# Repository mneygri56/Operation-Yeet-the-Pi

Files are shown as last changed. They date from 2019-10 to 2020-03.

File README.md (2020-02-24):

# Operation Yeet the Pi
Pi in the sky, by Miles and David. Also the story of how we ended up on several government watchlists.

*******DISCLAIMER, WE ARE DOING THIS UNDER A LOT OF SUPERVISON AND HAVE A LOT OF PEOPLE WHO KNOW WHAT THEY ARE DOING, THIS IS BY NO MEANS AN ENDORSEMENT OF ANY PROJECTS YOU MAY DO, AND THE FACT THAT WE ARE STILL ALIVE DOES NOT MEAN YOU WILL BE, PLEASE, <b>DO NOT TRY THIS AT HOME</b> ********* 

Thats a little aggressive, but it gets the point across, just to reiterate do not try this at home

That being said, here's how we did it
## A bad idea... or maybe not
The plan, if that's what we're going to call it, is to strap a pi onto a homemade rocket engine using [this recipe](https://www.wikihow.com/Make-Rocket-Fuel) for the fuel, and send that up. The final version of the rocket is going to be called the Kerbal XD after the Kerbal X from Kerbal Space Program.
## The Goal
Our goal is to launch a rocket as high as we can and collect data along the whole flight. (What Data to Collect). We are going to do a few tests of different additives of the fuel to increase thrust, and we will use this equation:

<a href="https://www.codecogs.com/eqnedit.php?latex=\LARGE&space;\Delta&space;v&space;=&space;v_{exhaust}*ln(\frac{m_{initial}}{m_{final}})" target="_blank">\LARGE \Delta v = v_{exhaust}*ln(\frac{m_{initial}}{m_{final}})</a>

To calculate how much fuel we should use to maximize delta v. The other values can be calculated from the test we will do and the rocket design. We could also have a height goal so that we can figure out exactly how fast we want the exhaust to go and how much fuel we need.

## Materials
| Material | Quantity | Cost |
|:---:|:---:|:---:|
| Potassium Nitrate(KNO<sub>3</sub>) | 58 grams (2.0 oz) per rocket | ~$7.00 per pound  |
| Granulated White Sugar | 29 grams (1.0 oz) per rocket | ~$2.00 for 4 pounds |
| Karo Corn Syrup |  13 milliliters (.43 floz) per rocket | ~$2.00 for 16 fl oz |
| Distilled Water | 30 milliliters (1.01 floz) per rocket | ~$0.80 for 1 gallon |

Cost = $25.80 Total, not including materials

Cost Turned out to be about $23
## Schedule

- Week One: 10/28 - 10/31
  + Planning: Start Project Plan
- Week Two: 11/6 - 11/8
  + Planning: Finish Project Plan, Seek Approval
    - Make Drawings
    - Do math that supports the design
    - Gather Materials
    - Make SolidWorks Model of Chassis
- Week Three: 11/11 - 11/15
  + Planning: Make Edits To Project Plan, Finalize and Submit
  + Make More Drawings!
- Week Four: 11/18 - 11/22
  + Buy Materials (Potassium Nitrate Specifically)
  + Test Batches - Different Additives and Force Plate
    - Use block period/afterschool
- Week Five: 11/25 - 11/29
  + Start Code: 
    - Make code to start the rocket
  + Revise SolidWorks Model
    - Do a Stress Analysis
    - Make sure there is room for wires
    - Make sure the Pi fits
  + Make predictions about how much fuel should be in the rocket
- Week Six: 12/2 - 12/6
  + Keep Coding:
    - Make Code to Log Acceleration
    - Make Code to Log other things
  + Build the SolidWorks model
    - In Real Life
    - Figure Out Materials
- Week Seven: 12/9 - 12/13
  + Make 2 Batches and Test:
    - Boil 'Em Mash 'Em Stick 'Em in a Stew
    - Don't Actually, its probably toxic
    - Test For lift, how much juice it outputs
- Weeks Eight to Ten:
  + Off For Winter Break and Midterms
- Week Eleven 1/6 - 1/10:
  + Make More Code:
    - Sound At Apex
    - Second Stage Activation and Timing
  + Build Rocket Engines:
    - Housing and Connection
- Week Twelve 1/13 - 1/17:
  + Build the Rocket:
    - Put it together
  + Finish Code:
    - Have the Code that will run on the Rocket
- Week Thirteen 1/20 - 1/24:
  + Assemble First Rocket Completely
    - Test Launch - 3 Motors, not full 6
  + Revise Code After Launch
- Week Fourteen 1/27 - 1/31:
  + Revise Code More:
    - See what worked
  + Revise Design Based on the Launch
    - Again, see what worked
- Week Fifteen 2/3 - 2/7:
  + Launch No. 2 - 4
    - Full 6 Motors
    - 3 Launches
  + Revise Code and Design
- Week Sixteen 2/10 - 2/14:
  + Launch No. 3 - 6
    - Full 6 Motors
    - 3 More 
  + Revise Design and Code
- Week Seventeen 2/17 - 2/21:
  + Launch No. 7-10
    - Full 6 Motors
- Week Eighteen 2/24 - 2/28:
  + Mess around with rocket fuel
    - Stick as many motors on as possible
- Week Nineteen 3/2 - 3/6:
  + Submit and Finish
  + We might be able to combine Eighteen and Nineteen
  
Well, a natural part of the engineering processs is revising. This schedule does not reflect how much testing we have to do, and how long the solidworks would take to finish. I think we have been a bit distracted, but We are still trying to finish by the end date of March 6th.

- Week 14: 1/27-1/31
  + I'd like to finish the solidworks model this week so that we can talk it over with Dr. Shields and finish revising it and print it.
  + Make Rust and Test it
- Week 15: 2/3-2/7
  + Revise the solidworks and hopefully be ready to print it
  + Make some rocket fuel with the rust, try to get 40-50g thrust
- Week 16: 2/10-2/14
  + Finalize the fuel mixture and fill boosters
  + Make sure code is ready to go
  + Prep for launch
- Week 17: 2/17-2/21
  + Get ready to assemble, update wiki with pics and vids
- Week 18: 2/24-2/28
  + David will be gone
  + Prep for launch, print stuff and get ready
- Week 19: 3/2-3/6
  + Launch on wed
  + Cool! Fun
- Week 20:
  + Submit and Finish
## Safety
I know our wikis and stuff are known for a bit of fun and jokes, but this part is serious, professional, and must not be joked around with.

There are multiple danger points in this project. This project can definitely go wrong. We must act with utmost care and respect for all of the forces and materials involved.

### Making the Fuel
This is probably the most dangerous part. We are going to be heating up flammable materials to get them to congeal into a solid block. [Here](https://www.wikihow.com/Make-Rocket-Fuel?scrlybrkr=71c97d6e) is the procedure for making the fuel and [here](http://www.jamesyawn.net/rcandy/safety.htm) is one of the best places to see the risks and danger points involved. The most dangerous part of making the fuel according to this source is scraping the fuel and shaping it. I agree, and we must be careful. Additionally, here more precautions that must be taken:

- Have an ABC fire extinguisher on hand in case fire breaks out. Worst case scenario is that fire breaks out in the pan and we are close to it. The first thing that must be done in case of this is to put out the fire. This reaction is self sustaining and powerful, so we cannot rely on just the heat being turned off.
  - Two people must be on hand while cooking, ideally three. One to cook the mixture, one to get help in case of a fire and the person cooking is incapacitated, and one to put out the fire. All jobs are important, but the two most important are the cooking and putting out the fire, getting help can be taken care of by the person cooking if they are not incapacitated by the fire from the mixture.
- Do all of it outside, it will minimize damage if fire breaks out, and will provide an easy way for the fumes to escape without harming us.
- Store the finished rocket fuel in a plastic container in the storage room if possible, this will reduce the risk of people thinking they can mess with the fuel once we are done. 
### Launches
This is the other part where things can go wrong. A stray launch can go into someone's face with a lot of force, burn a lot of grass, so on and so forth. Here are some additional concerns to be aware of when launching rockets.

- Make sure the launch area is clear and people are standing well back, this will make sure that things do not catch fire, and that people will not be hurt by the launch.
- Launch on pavement if possible - if not, put down a piece of metal or other inflammable material under the launch site, this will reduce the risk of fire from grass under the launch site. Additionally, we may consider using one of those launch platforms so that the launch will be straight, in addition to not catching the grass on fire.
- Keep landing site clear, This is a big one - we don't know where the rocket will land, so if possible, we want to make sure it lands in an unpopulated area, of cars and people, in case a parachute cannot slow it down enough to where it won't break a car's winshield if it lands on it. Additionally, some fuel may be left unreacted, so we don't want it to burn on the ground - Consider putting a gps reciever on it so we can keep track of where it is.
- Put a parachute in the end so that when it starts its downward approach, it won't be going as fast so it is less dangerous.
- Apparently there are rules against putting massive amounts of rocket fuel on plastic and shooting it as high as it will go, so we are only going to use two engines to avoid being sued by the FAA
## Questions to consider
(Put Answers below as we discuss)
- What should we put on the rocket? What do we need?
   - accelerometer
   - Piezo Buzzer
   - Pi
   - Wires
   - Altimeter
   - battery
- What additives should we test?
  - Rust Powder 
- What should we make the chassis out of? The engine housing? Pi camera housing? Others?
  - Metal
  - Foam
  - ABS-PC
- Parachute? If so, how will it deploy? If not, how do we reduce the risk of crashing and burning? Use McIntire Park? Milton Airfield? What permits, if any, will we need to do it at these places?
  - propellor? (probably not)
  - "Nerf Sword" prinicple
    - Plastic Shell covered in foam (metal)
  - actual parachute
- How are we going to reduce weight so it gets as high as possible?
  - Skeletonized Parts
  - Bare Minimum Wires
  - Plastic
## Rocket Specs

### Fuel Info
The fuel is made of Potassium Nitrate, sucrose, and brown iron rust at a ratio of 65:35:1. The general process is to heat up the three ingredients until the sugar and potassium nitrate melt to create a liquidy substance, stirring constantly. The beaker is then taken off the heat and the fuel is scooped into the rocket booster. It is then packed by tamping it with the head of a nail. After talking to a rocket person, This process may be revised to packing the fuel into a cardboard tube to make an engine before actually placing the motor into the ABS-PC receptacle. 

### Grain Geometry
The grain geometry is an important consideration when assessing burn rates and thrust. We have been using a simple flat surface, but we have been considering drilling a hole in the middle of the engine to have larger thrust on liftoff, and the thrust will increase over the flight.

### Fuselage Info
The fuselage is made of a cylinder of ABS PC with a hole in the middle for the raspberry pi, recovery servo, and other sensors. More information is in the solidworks models, or in the pictures section.

### Recovery
We are planning to use a parachute from an estes kit to recover the rocket. The recovery servo will push the platform that the parachute is resting on up so that the parachute will pull away from the top as the rocket slows down at the top of its arc. For this reason, there is no nose cone. This acts as a fail safe if the rocket starts going out of control, the parachute will fall away from the rocket and deploy because the parachute was being held on by the speed that the rocket was going.

### Nozzle
The nozzle is a piece of ABS-PC that covers the end of the engine with a 10mm hole in the middle.

## Sources
I have a feeling I will be referencing this a lot:

Munroe, Randall. “Rocket Golf.” Rocket Golf, Xkcd, [Rocket Golf](what-if.xkcd.com/85/).

Nakka, Richard. “Determining Total Impulse and Specific Impulse from Static Test Data.” Richard Nakka's Experimental Rocketry Site, 2000, [www.nakka-rocketry.net/impcalc.html](www.nakka-rocketry.net/impcalc.html).

## Calculations

<a href="https://www.codecogs.com/eqnedit.php?latex=\LARGE&space;\Delta&space;v&space;=&space;v_{exhaust}*ln(\frac{m_{initial}}{m_{final}})" target="_blank">\Delta v = v_{exhaust}*ln(\frac{m_{initial}}{m_{final}})</a>

<a href="https://www.codecogs.com/eqnedit.php?latex=&space;v_{exhaust}=I_{sp}g_{0}" target="_blank">v_{exhaust}=I_{sp}g_{0}</a>

<a href="https://www.codecogs.com/eqnedit.php?latex=&space;g_0&space;=&space;9.806\frac{m}{s^2}" target="_blank">g_0 = 9.806\frac{m}{s^2}</a>

<a href="https://www.codecogs.com/eqnedit.php?latex=&space;I_{sp}=120s" target="_blank">I_{sp}=120s</a>

<a href="https://www.codecogs.com/eqnedit.php?latex=\LARGE&space;v_{exhaust}=120s*9.806\frac{m}{s^2}=1176.72\frac{m}{s}" target="_blank">v_{exhaust}=120s*9.806\frac{m}{s^2}=1176.72\frac{m}{s}</a>

<a href="https://www.codecogs.com/eqnedit.php?latex=m_{fin}=444g" target="_blank">m_{fin}=444g</a>

<a href="https://www.codecogs.com/eqnedit.php?latex=\Delta&space;v=1176.72ln(\frac{m_{fuel}&plus;444}{444})" target="_blank">\Delta v=1176.72ln(\frac{m_{fuel}+444}{444})</a>

## Some Documentation
### Pictures
Should have started this sooner, but here:

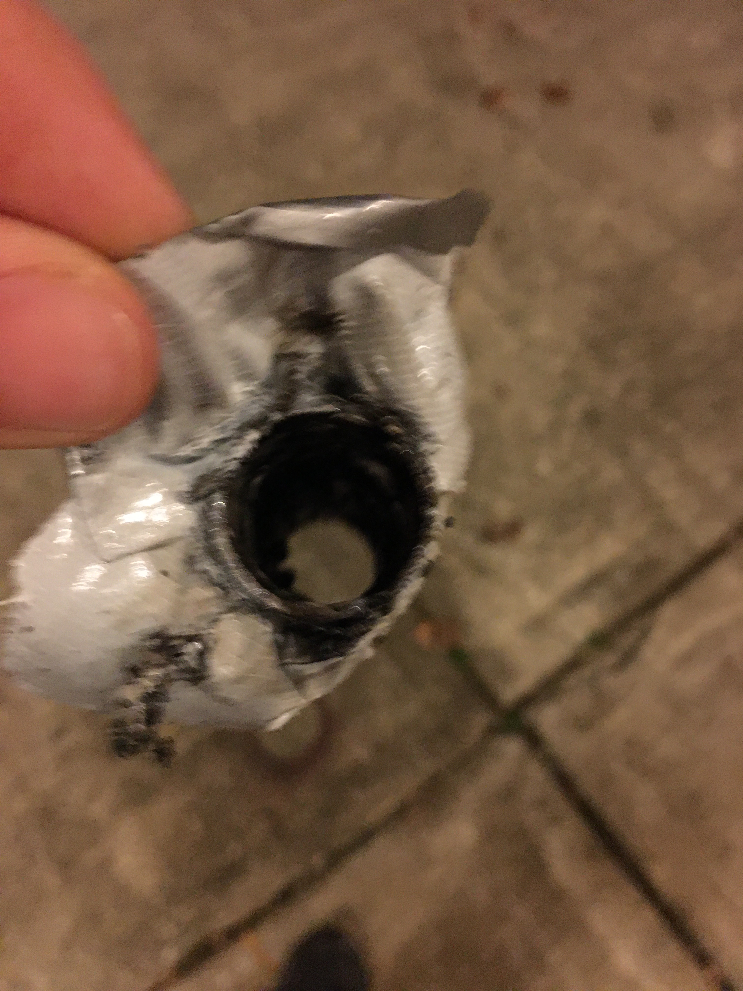
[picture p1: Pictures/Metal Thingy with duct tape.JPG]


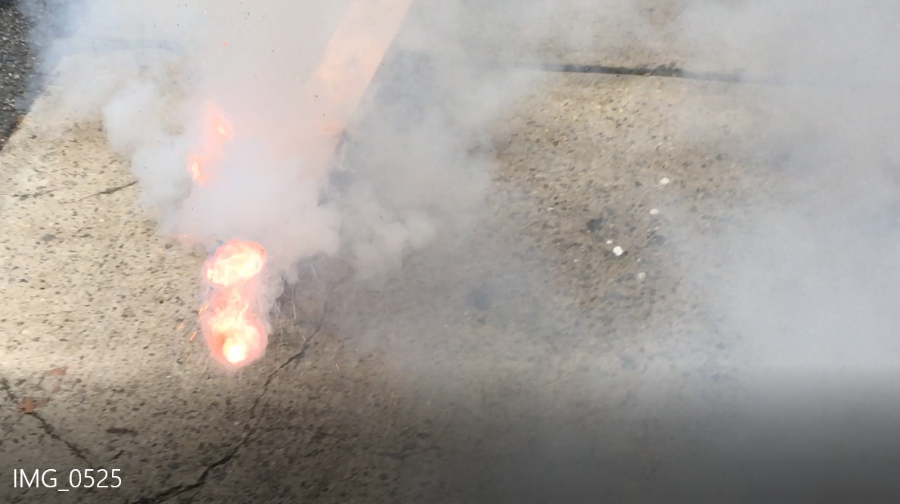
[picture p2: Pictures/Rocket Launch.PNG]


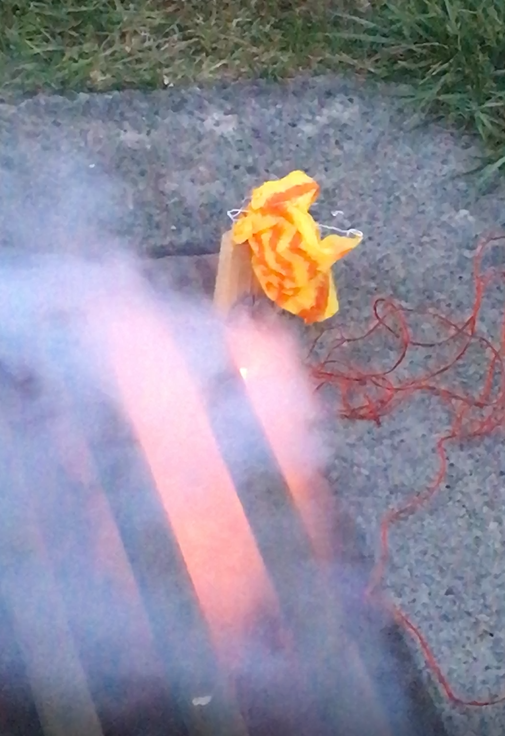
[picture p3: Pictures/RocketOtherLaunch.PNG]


[Making Rust](https://youtu.be/RcKSFwdpVkA)

[Testing Rocket](https://youtu.be/CEroAyz3F4E)

[Another One](https://youtu.be/RToPVv3NRZM)

### Weekly Progress Report
This starts from the first milestone, 11/22

#### 11/22
Well, we made a batch, but it didn't really work. I couldn't really tell you why, but we have a few guesses
- The stuff wasn't dry -very likely
- It doesn't work and we are failures -less likely

It made a really cool firey thing though
#### 11/29
We forgot about thanksgiving break, and we didn't accomplish everything we set out to do. We are thinking we can't start our rocket with the pi, so maybe just use a blowtorch, we'll see if the starters can actually start the rocket fuel, but we might need to use the blowtorch. 

In other news, we got a pretty good model of the rocket in solidworks, all we have to do now is add a servo so that we can take the top off whenever we want to.
#### 12/6
We have most of a solidworks model, its not completely done, but we are close, just having to resolve all these random errors that are weird. We also added a few videos and pictures of a cool launch that finally worked where Dr. Shields almost shot himself in the leg! to the github Cool! Additionally, there is now a bunch of code for logging acceleration data and taking video. We have yet to print the model, but we are still on schedule.
#### 12/13

#### 1/10

#### 1/17
This week, we started revising the solidworks model so that it took the least amount of material to print, and it was as small as possible. We did this so that the boosters could lift the model, and so that it used not that much material. I feel like we are behind schedule, but I'll let it slide.
#### 1/24

#### 1/31

#### 2/7

#### 2/14

#### 2/21

#### 2/28

#### 3/6

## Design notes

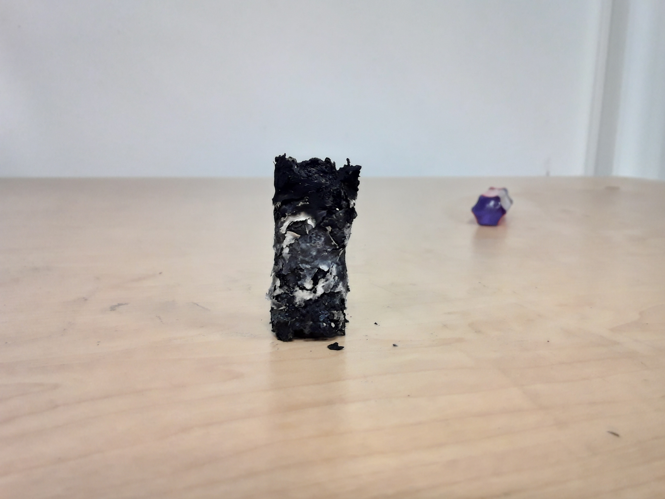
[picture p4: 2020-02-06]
Pictures/Burned out rocket booster, back of a screwdriver for scale.jpg

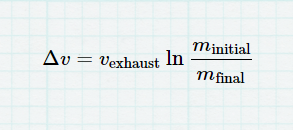
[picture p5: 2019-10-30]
Pictures/RocketEquation.PNG

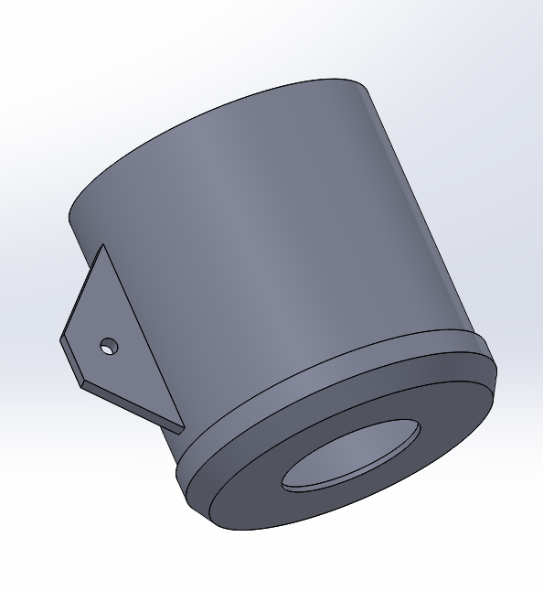
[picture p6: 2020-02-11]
Pictures/Booster.PNG

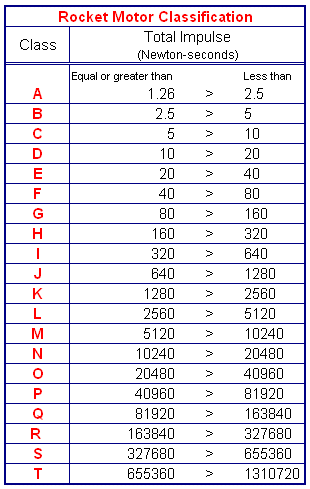
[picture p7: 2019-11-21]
Pictures/mot_clas.gif

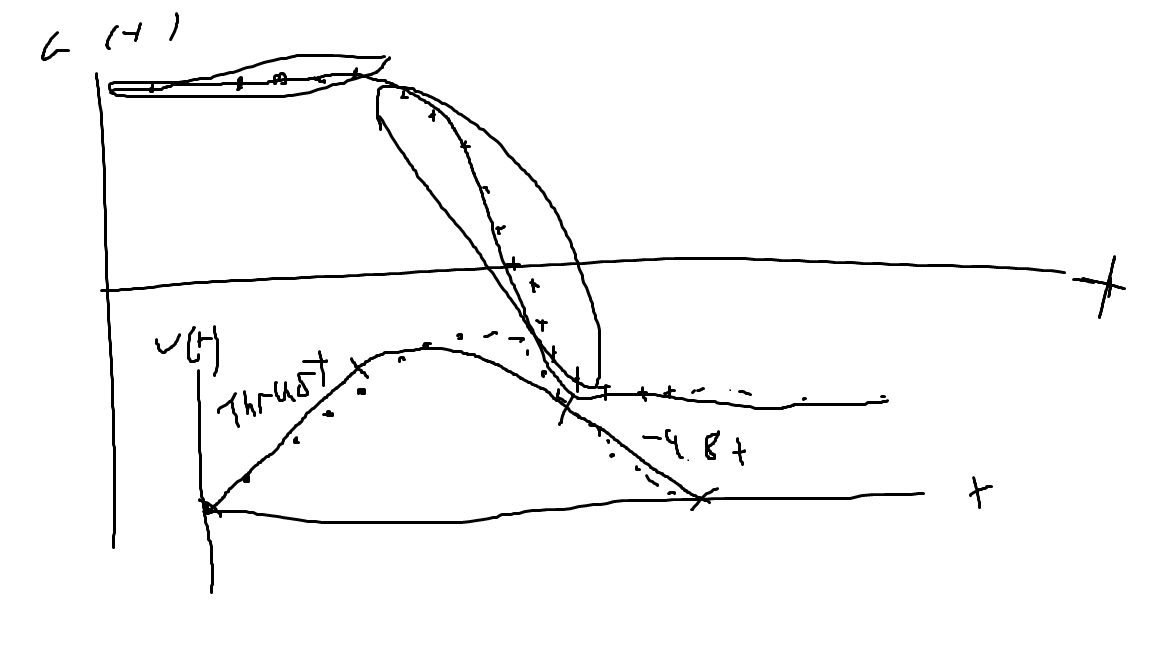
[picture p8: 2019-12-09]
Pictures/Rocket Graph.png

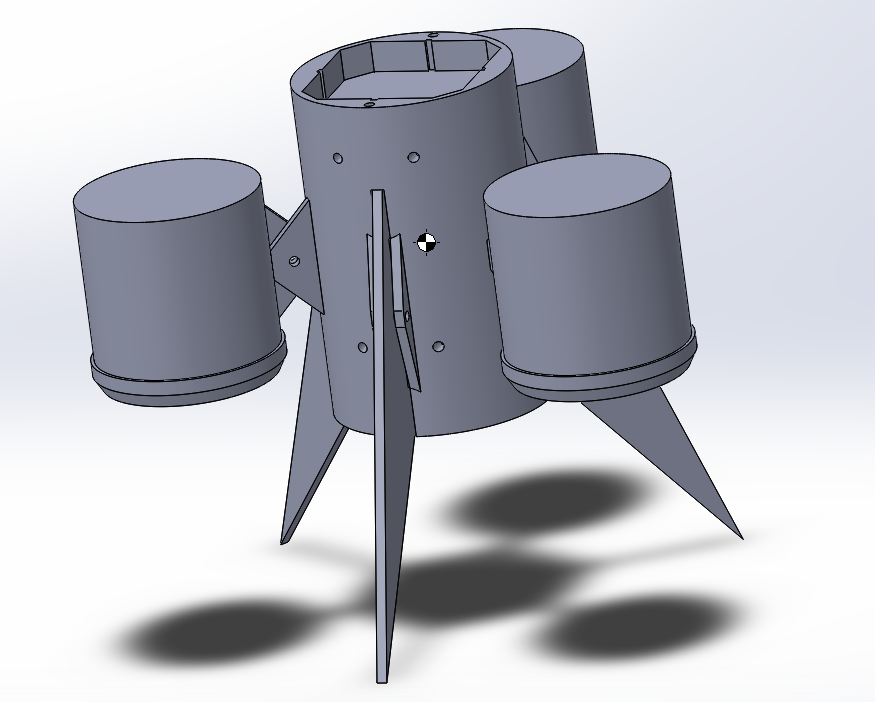
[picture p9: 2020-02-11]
Pictures/Full Rocket.PNG

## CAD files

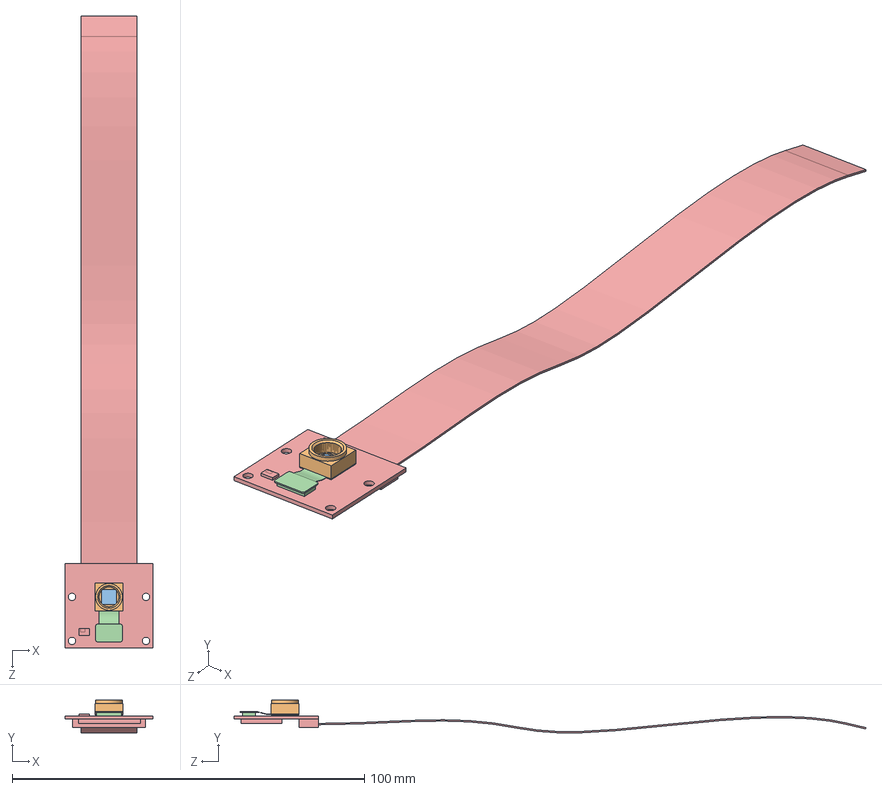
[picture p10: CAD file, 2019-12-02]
Rocket CAD/PiCamera/RasPi_Camera.SLDASM
25.0 x 9.29 x 179.3 mm
OVA5647
OVA5647_Housing
OVA5647_IR-Glas
OVA5647_Pigtail
RasPi_Camera_Board

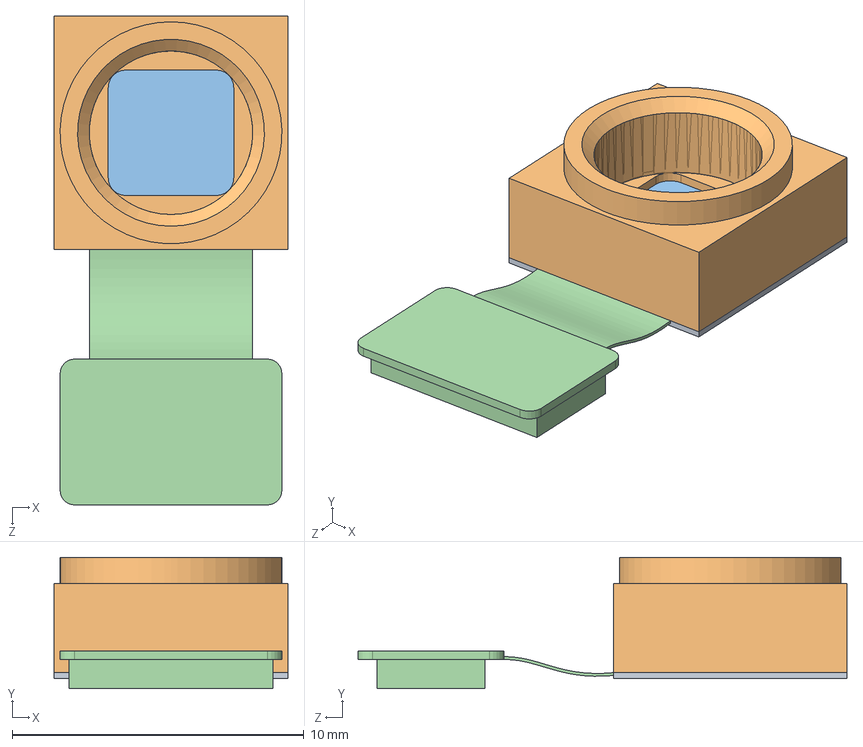
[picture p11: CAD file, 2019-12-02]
Rocket CAD/PiCamera/OVA5647.SLDASM
8.00 x 4.50 x 16.8 mm
OVA5647
OVA5647_Housing
OVA5647_IR-Glas
OVA5647_Pigtail

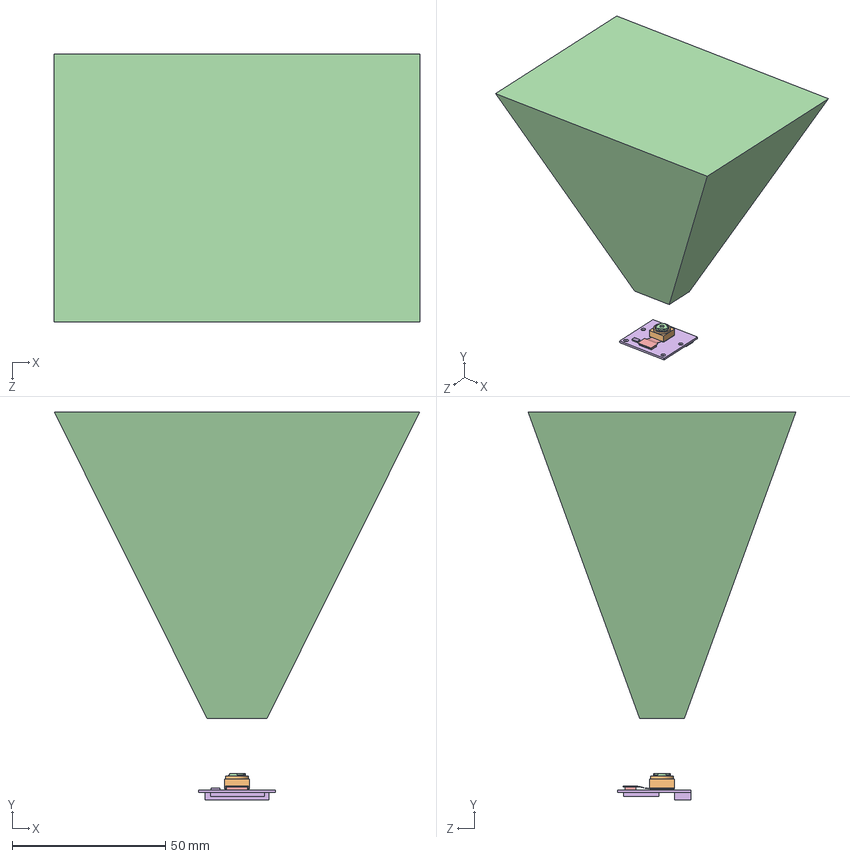
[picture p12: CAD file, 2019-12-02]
Rocket CAD/PiCamera/RasPi_Camera_Simple.SLDASM
119.2 x 126.5 x 87.4 mm
OVA5647
OVA5647_Housing
OVA5647_IR-Glas
OVA5647_Pigtail
RasPi_Camera_Board

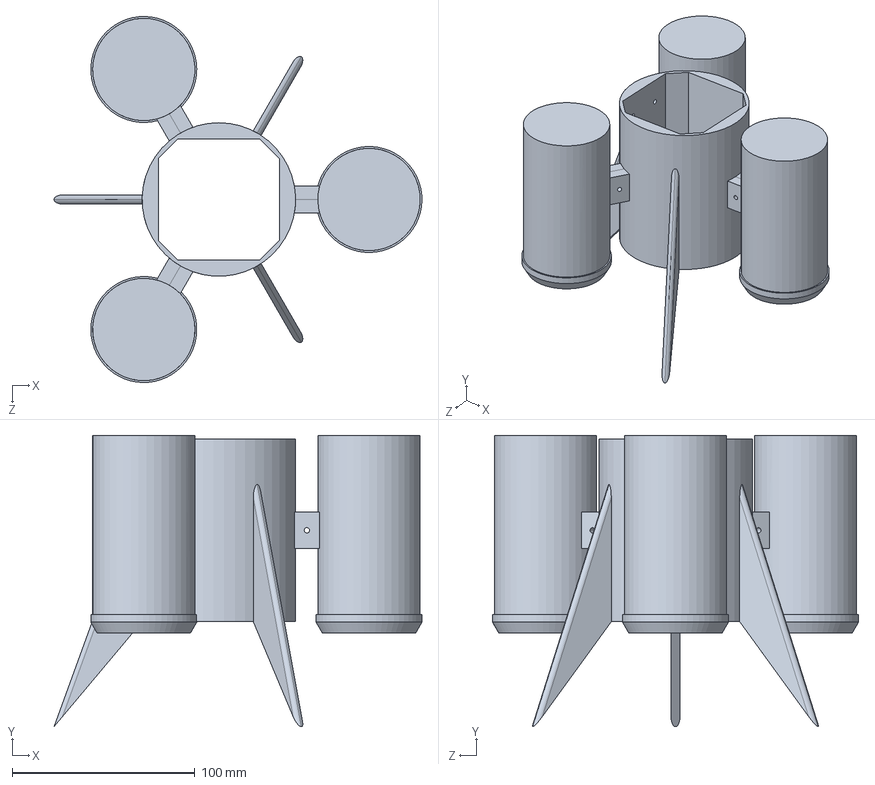
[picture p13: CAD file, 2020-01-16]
Rocket CAD/RocketAssembly.SLDASM
201.4 x 159.5 x 200.3 mm
Rocketbodies x 7

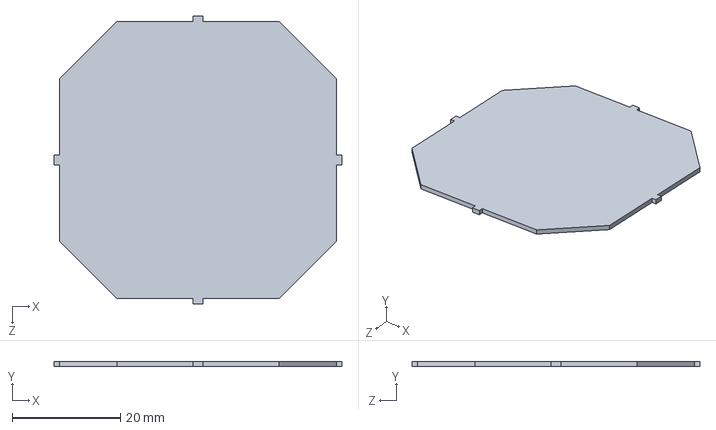
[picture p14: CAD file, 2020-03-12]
Rocket CAD/Flat Thingy.SLDPRT
53.2 x 1.00 x 53.2 mm

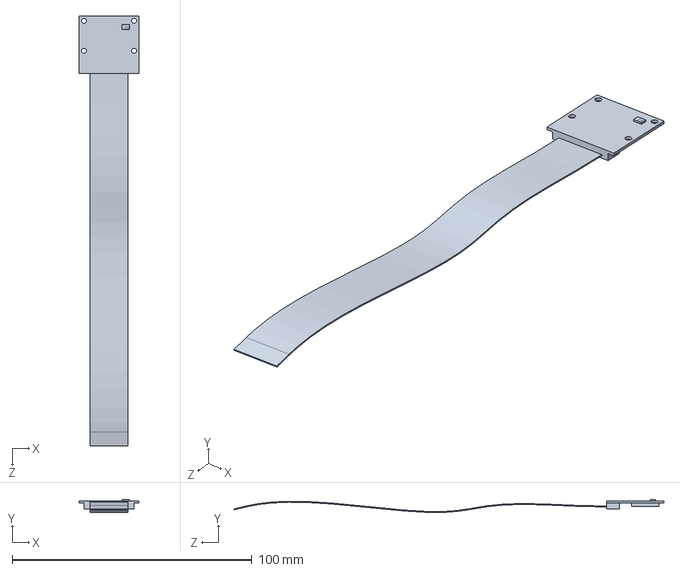
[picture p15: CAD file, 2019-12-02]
Rocket CAD/PiCamera/RasPi_Camera_Board.SLDPRT
25.0 x 5.39 x 179.3 mm

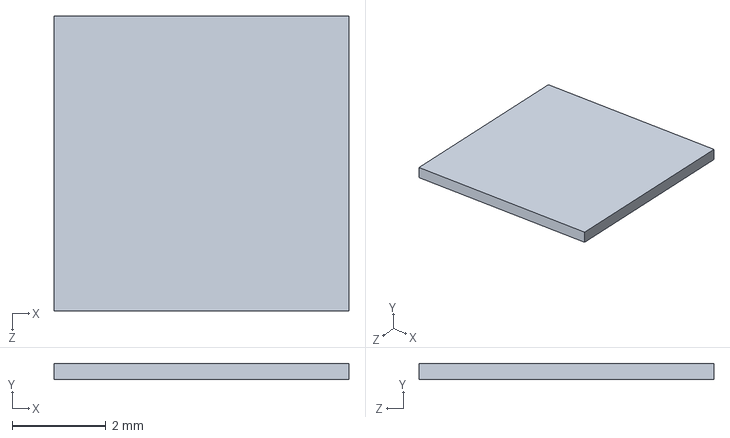
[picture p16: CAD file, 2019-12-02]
Rocket CAD/PiCamera/OVA5647_IR-Glas.SLDPRT
6.30 x 0.35 x 6.30 mm

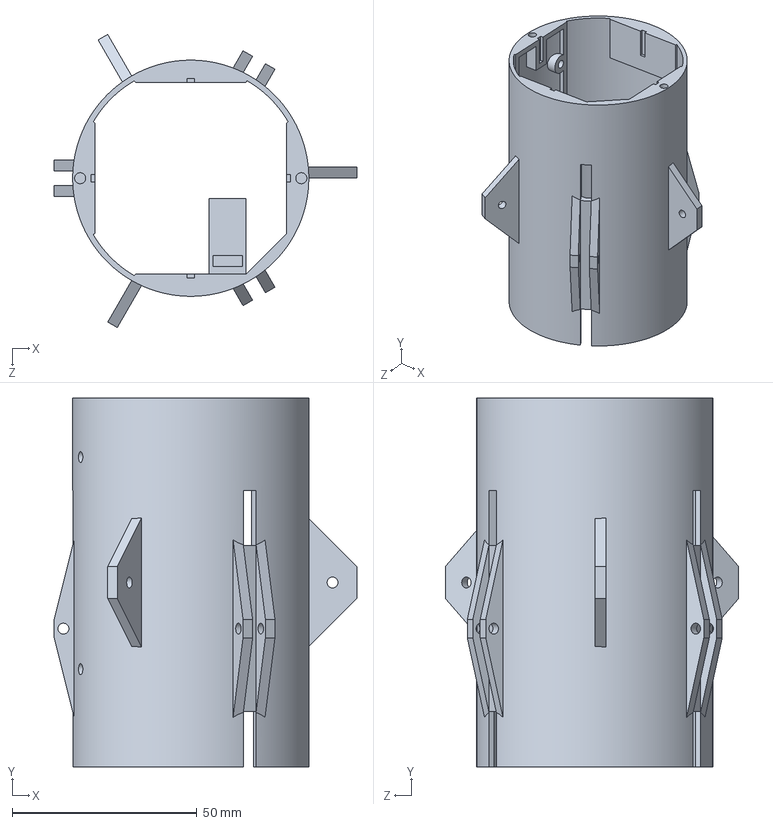
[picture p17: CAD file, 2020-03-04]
Rocket CAD/Rocketbodies.SLDPRT
82.0 x 100.0 x 79.4 mm

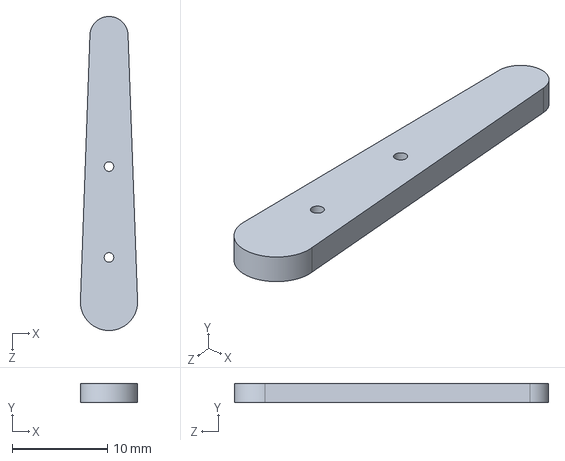
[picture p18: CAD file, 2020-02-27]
Rocket CAD/Arm.SLDPRT
6.00 x 2.00 x 32.9 mm

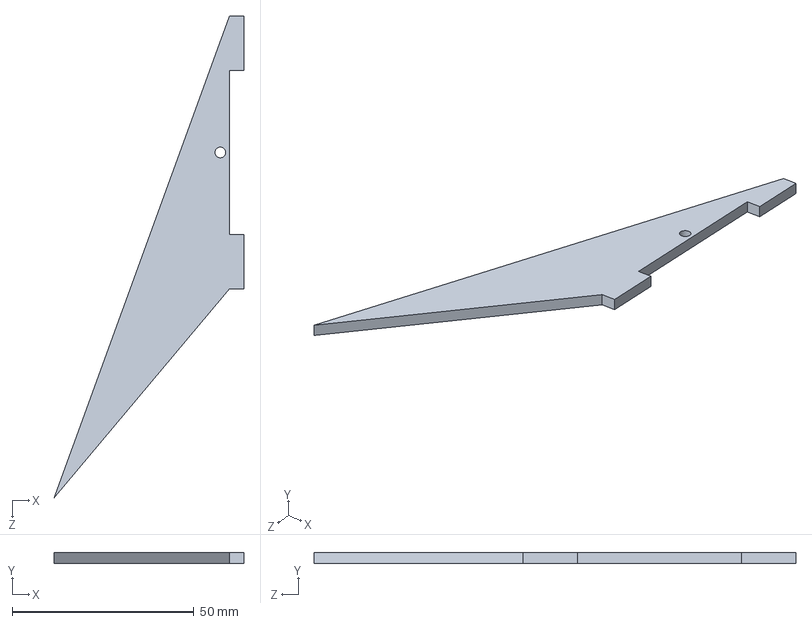
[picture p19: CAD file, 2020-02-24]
Rocket CAD/Wings.SLDPRT
52.2 x 3.00 x 132.5 mm

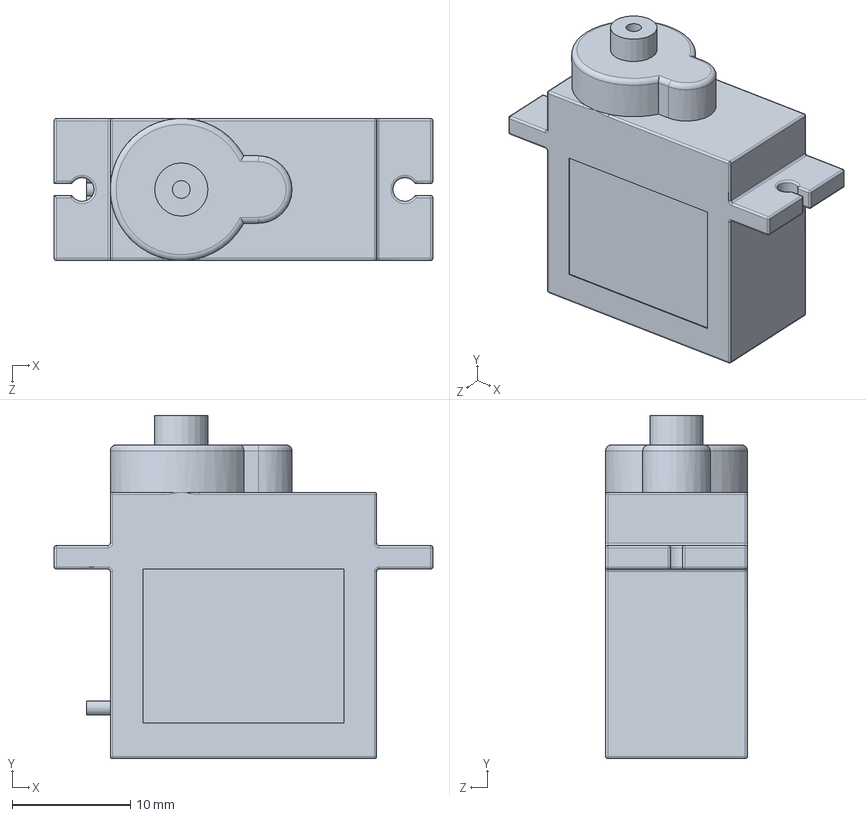
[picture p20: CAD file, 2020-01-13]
Rocket CAD/Micro Servo FS90R Continuous.SLDPRT
32.0 x 29.0 x 12.0 mm

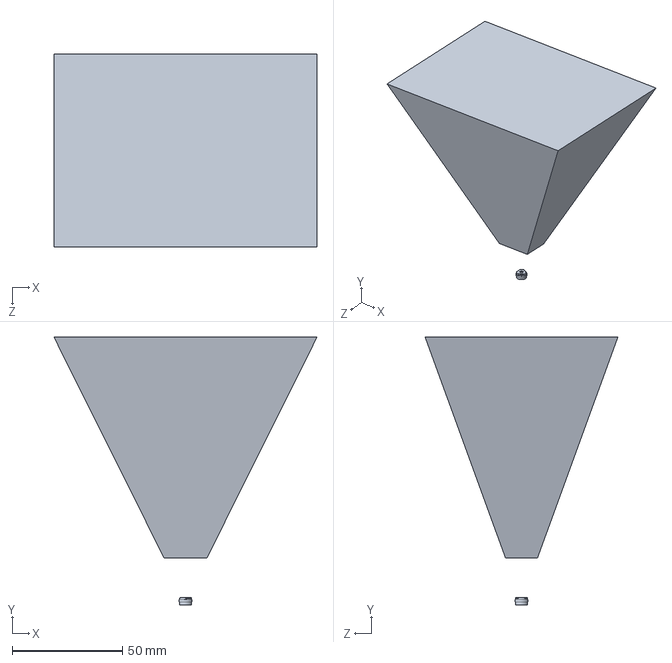
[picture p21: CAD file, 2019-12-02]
Rocket CAD/PiCamera/OVA5647_Lens.SLDPRT
119.2 x 121.3 x 87.4 mm

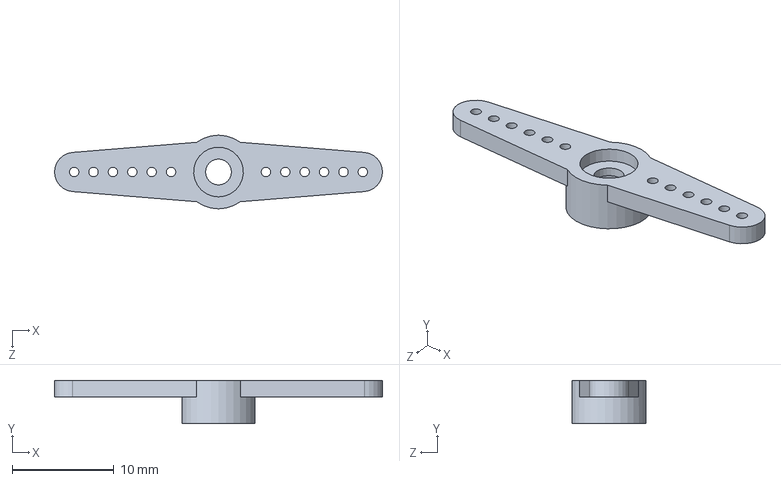
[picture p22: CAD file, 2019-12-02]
Rocket CAD/Micro Servo Horn Double Arm.SLDPRT
32.2 x 4.23 x 7.24 mm

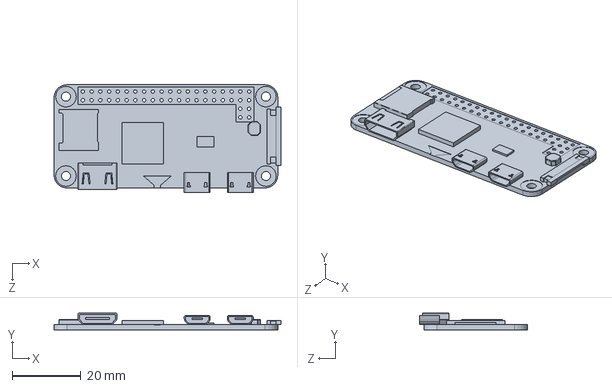
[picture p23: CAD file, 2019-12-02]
Rocket CAD/RaspberryPiZeroW.SLDPRT
65.9 x 4.80 x 31.2 mm

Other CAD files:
Rocket CAD/Flat thingy recut.SLDDRW
Rocket CAD/Lasercut Stuff.SLDDRW
Rocket CAD/PiCamera/OVA5647.SLDPRT

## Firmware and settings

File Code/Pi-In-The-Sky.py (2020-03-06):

import time

import Adafruit_LSM303
from picamera import PiCamera
import RPi.GPIO as GPIO
import math
import smbus

# Get I2C bus
bus = smbus.SMBus(1)

# MPL3115A2 address, 0x60(96)
# Select control register, 0x26(38)
#		0xB9(185)	Active mode, OSR = 128, Altimeter mode
bus.write_byte_data(0x60, 0x26, 0xB9)
# MPL3115A2 address, 0x60(96)
# Select data configuration register, 0x13(19)
#		0x07(07)	Data ready event enabled for altitude, pressure, temperature
bus.write_byte_data(0x60, 0x13, 0x07)
# MPL3115A2 address, 0x60(96)
# Select control register, 0x26(38)
#		0xB9(185)	Active mode, OSR = 128, Altimeter mode
bus.write_byte_data(0x60, 0x26, 0xB9)

time.sleep(1)
#Initialize the accellerometer
lsm303 = Adafruit_LSM303.LSM303()

#Initialize the camera
myCamera = PiCamera()

#Get the starting time
start_time = time.time()

#Initialize the servo
parachuteServoPin = 17
GPIO.setmode(GPIO.BCM)
GPIO.setup(parachuteServoPin, GPIO.OUT)
p2 = GPIO.PWM(parachuteServoPin, 50) # GPIO 18 for PWM with 50Hz
p2.start(2.5) #Initialize to 90

buzzerPin = 14
GPIO.setup(buzzerPin, GPIO.OUT)

accelValsBeforeMotor = [[0,0,0,0]]

beeped = False
secsPerYear = 60*60*24*365
#make a file to log accelleration data:
startYear = 1970 + math.floor(start_time/31556926)
startMonth = math.floor((start_time%31556926)/2629743)
startDay = math.floor(((start_time%31556926)%2629743)/86400)
startHr = math.floor((((start_time%31556926)%2629743)%86400)/3600)
startMin = math.floor(((((start_time%31556926)%2629743)%86400)%3600)/60)
startSec = math.floor(((((start_time%31556926)%2629743)%86400)%3600)%60)
f= open("Accel_From"+str(startMonth)+"."+str(startDay)+"."+str(startYear)+", "+str(startHr)+"."+str(startMin)+"."+str(startSec)+".txt", "w+")

#make a map function for the servo and acsellerometer values
def realMap(number, lowFirst, highFirst,lowSecond, highSecond):
	newNumber =(number-lowFirst)/(highFirst-lowFirst)*(highSecond-lowSecond)+lowSecond
	return newNumber

def beep():
	GPIO.output(buzzerPin, GPIO.HIGH)
	time.sleep(.1)
	GPIO.output(buzzerPin, GPIO.LOW)
	time.sleep(.1)
#Start recording the camera
myCamera.start_recording('thrustCam'+str(startMonth)+"."+str(startDay)+"."+str(startYear)+", "+str(startHr)+"."+str(startMin)+"."+str(startSec)+'.h264')
myCamera.start_preview(alpha = 155)
currTime = time.time()-start_time
while currTime<120:
             data = bus.read_i2c_block_data(0x60, 0x00, 6)
             # MPL3115A2 address, 0x60(96)
             # Select control register, 0x26(38)
             #		0xB9(185)	Active mode, OSR = 128, Altimeter mode
             bus.write_byte_data(0x60, 0x26, 0xB9)
             # MPL3115A2 address, 0x60(96)
             # Select data configuration register, 0x13(19)
             #		0x07(07)	Data ready event enabled for altitude, pressure, temperature
             bus.write_byte_data(0x60, 0x13, 0x07)
             # MPL3115A2 address, 0x60(96)
             # Select control register, 0x26(38)
             #		0xB9(185)	Active mode, OSR = 128, Altimeter mode
             bus.write_byte_data(0x60, 0x26, 0xB9)
             time.sleep(1)
             # Convert the data to 20-bits
             data = bus.read_i2c_block_data(0x60, 0x00, 6)
             tHeight = ((data[1] * 65536) + (data[2] * 256) + (data[3] & 0xF0)) / 16
             temp = ((data[4] * 256) + (data[5] & 0xF0)) / (16)
             altitude = tHeight / (16.0)
             cTemp = temp / 16.0
             fTemp = cTemp * 1.8 + 32
             # MPL3115A2 address, 0x60(96)
             # Select control register, 0x26(38)
             #		0x39(57)	Active mode, OSR = 128, Barometer mode
             bus.write_byte_data(0x60, 0x26, 0x39)

             time.sleep(1)
             # MPL3115A2 address, 0x60(96)
             # Read data back from 0x00(00), 4 bytes
             # status, pres MSB1, pres MSB, pres LSB
             data = bus.read_i2c_block_data(0x60, 0x00, 4)
             # Convert the data to 20-bits
             pres = ((data[1] * 65536) + (data[2] * 256) + (data[3] & 0xF0)) / 16
             pressure = (pres / 4.0) / 1000
             #get the current time
             currTime = time.time()-start_time


             #get the accelllerometor values and map them to m/s^2
             accel, mag = lsm303.read()
             accel_x, accel_y, accel_z = accel
             x = realMap(accel_x, -1000, 1000, -9.81, 9.81)
             y = realMap(accel_y, -1000, 1000, -9.81, 9.81)
             z = realMap(accel_z, -1000, 1000, -9.81, 9.81)

             #Append these values so we can get the accelleration data
             f.write(str(x)+" (x)m/s^2, "+str(y)+" (y)m/s^2, "+str(z)
                +" (z)m/s^2,\n"+str(pressure)+"kPa\n"+str(altitude)+"m\n"
                +str(cTemp)+"deg C\n"+str(currTime)+"seconds\n")
             f.flush()
             #If the velocity is low, beep
             if currTime>30 and not beeped:
                beep()
                beeped = True
             #set the servo position and map it to the duty cycle so it can be used
             if(currTime>30):
                parachuteServoPos = 90
             else:
                parachuteServoPos = 0
             parachuteCycle = realMap(parachuteServoPos, 0, 180, 2.5, 12.5)
             p2.ChangeDutyCycle(parachuteCycle)
myCamera.stop_recording()
myCamera.stop_preview()
GPIO.cleanup()
p2.stop()
f.close()

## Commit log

2019-11-21 Added a motor class file
2019-12-02 Added the CAD and Code
    Pretty Self-Explanatory
    [Micro Servo FS90R Continuous.SLDPRT, Micro Servo Horn Double Arm.SLDPRT, OVA5647.SLDASM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]
2019-12-03 changed some things so less errors when run
    [Pi-In-The-Sky.py]
2019-12-10 CAD Synchronization
    [Rocketbodies.SLDPRT, global_parameters.txt]
2019-12-12 Removed Launch Sequence
    Added a second servo for parachute deployment
2020-01-13 Assorted CAD changes
    [Flat Thingy.SLDPRT, Micro Servo FS90R Continuous.SLDPRT, RocketAssembly.SLDASM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]
2020-01-28 More CAD Stuff
    Solidworks makes me suffer.
    [Arm.SLDPRT, Flat Thingy.SLDPRT, Rocketbodies.SLDPRT]
2020-01-30 Made Tab Thingies
    I will fly to France and commit arson. Y'all know why.
    [Flat Thingy.SLDPRT, Rocketbodies.SLDPRT]
2020-01-31 Fixed the code,
    it now works on the pi, it should be ready for launch now.
    [Pi-In-The-Sky.py]
2020-01-31 More CAD
    Okay, braces are complete on the mounting points for the booster. Also did the parachute platform's guide channels.
    [Flat Thingy.SLDPRT, Rocketbodies.SLDPRT]
2020-02-03 Creating The wing pieces
    [Wings.SLDDRW, Wings.SLDPRT]
2020-02-04 More CAD
    More madness.
    [Rocketbodies.SLDPRT, Wings.SLDPRT]
2020-02-11 Cad
    ? IDK what changes these are.
2020-02-24 I think the cads done
    The fact that I think that means I probably have like another week of fixing stuff ahead of me.
    [Flat Thingy.SLDPRT, Rocketbodies.SLDPRT, Wings.SLDPRT]
2020-02-24 Lasercut stuff
    Made up the composite .slddrw and .ai files for lasercutting. Knew I wasn't done with solidworks. /sigh
    [Lasercut Stuff.SLDDRW, Wings.SLDDRW]
2020-02-25 Last change on the model
    Cut down the fuselage's volume by ~2 square inches. Trigger has been pulled, the rocket is printing.
    [Rocketbodies.SLDPRT]
2020-02-27 More Cad
    You thought we were done?! Changed the servo arm so it would get more torque.
    [Arm.SLDPRT]
2020-02-28 FFS SOLIDWORKS
    Why do you default to 2:1 on your drawings?
    [Flat thingy recut.SLDDRW, Lasercut Stuff.SLDDRW, Rocketbodies.SLDPRT]
2020-03-04 FAUUASDOUIASDOIASD
    I am going to lose my mind.
    [Flat Thingy.SLDPRT, Flat thingy recut.SLDDRW, Rocketbodies.SLDPRT]
2020-03-06 Code and CAD
    You think you know who committed this. But it is I, Miles.
    [Flat Thingy.SLDPRT, Flat thingy recut.SLDDRW]
2020-03-12 I hate solidworks
    [Flat Thingy.SLDPRT, Flat thingy recut.SLDDRW]
2020-03-13 Added PCB files
    [Untitled Sketch_contour.gm1, Untitled Sketch_copperBottom.gbl, Untitled Sketch_copperTop.gtl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]
